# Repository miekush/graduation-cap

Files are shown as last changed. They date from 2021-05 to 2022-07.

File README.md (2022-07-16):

# Graduation Cap
A simple LED sequencer based Graduation Cap

This is a pretty simple LED Graduation cap reference design I made for the upcoming graduation ceremony of my BSEE! It's circuit is based on my [N-Output Sequencer](https://github.com/mkengineering/N_Output_Sequencer) reference design and could be easily modified for other students to use in their own ceremony.

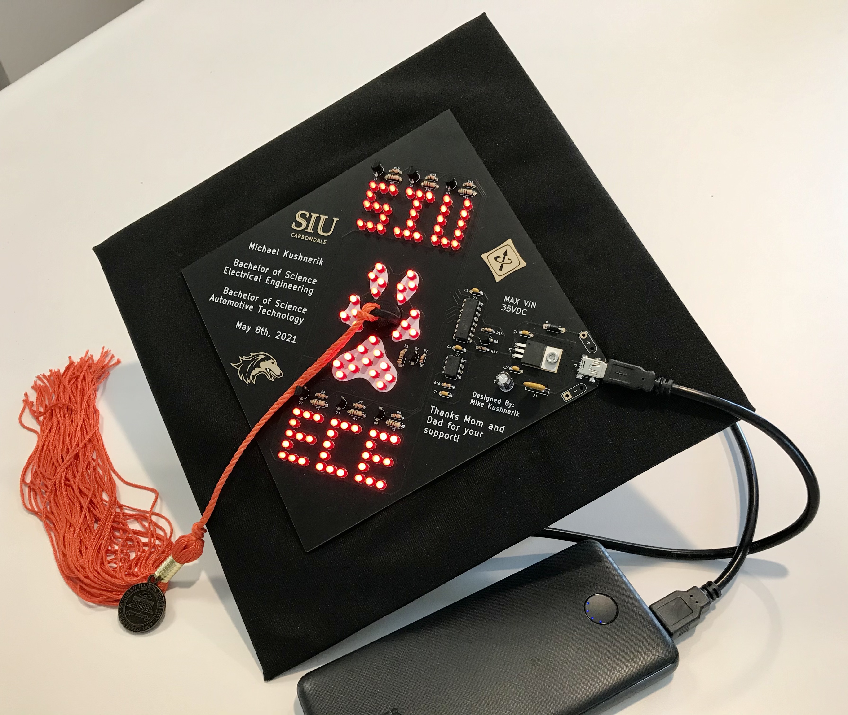
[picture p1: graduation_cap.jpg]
CAP


# Gerber View

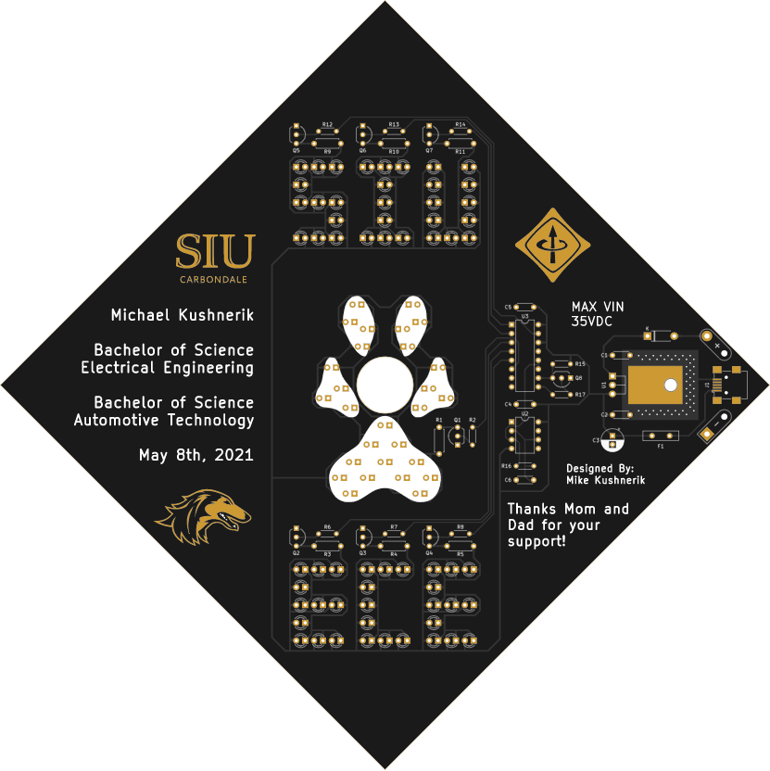
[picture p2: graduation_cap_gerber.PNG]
PCB


# Tassel Holder

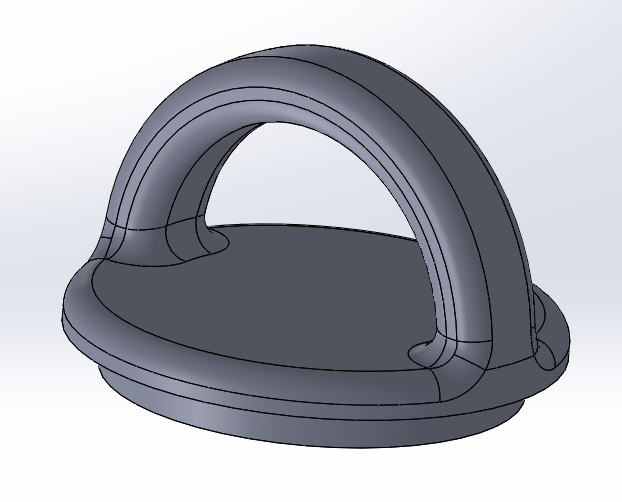
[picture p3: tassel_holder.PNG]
TASSEL


Unfortunatly I wasn't able to get good measurements of the original button that holds the tassel on top of the cap prior to designing the PCB, so the hole I added for it to pass through ended up being too small :cry:. To remedy this, I designed a glue-in 3D printable loop to tie the tassel around. Definitely not ideal but it works great for what it is! Check out the Tassel Holder folder for the solidworks design file and stl!

Designed by Mike Kushnerik (MKE) in KiCad V5

# License

MKE supports the open source hardware community by sharing hardware design files freely on GitHub!

Please support MKE by purchasing products on [Tindie](https://www.tindie.com/stores/mkengineering/)!

Designed by Mike Kushnerik for MKEngineering

Licensed under [Creative Commons Attribution-ShareAlike CC BY-SA 3.0](http://creativecommons.org/licenses/by-sa/3.0/)

All text above must be included in any redistribution!

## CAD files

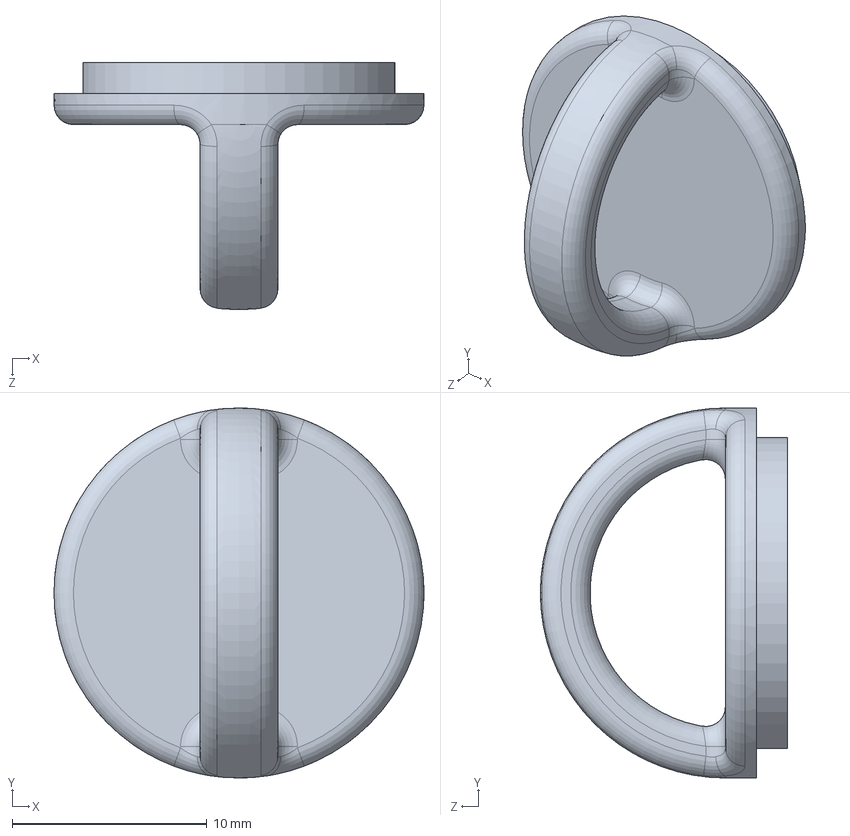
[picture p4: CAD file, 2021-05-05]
Tassel Holder/tassel_holder.SLDPRT
19.0 x 19.0 x 12.7 mm

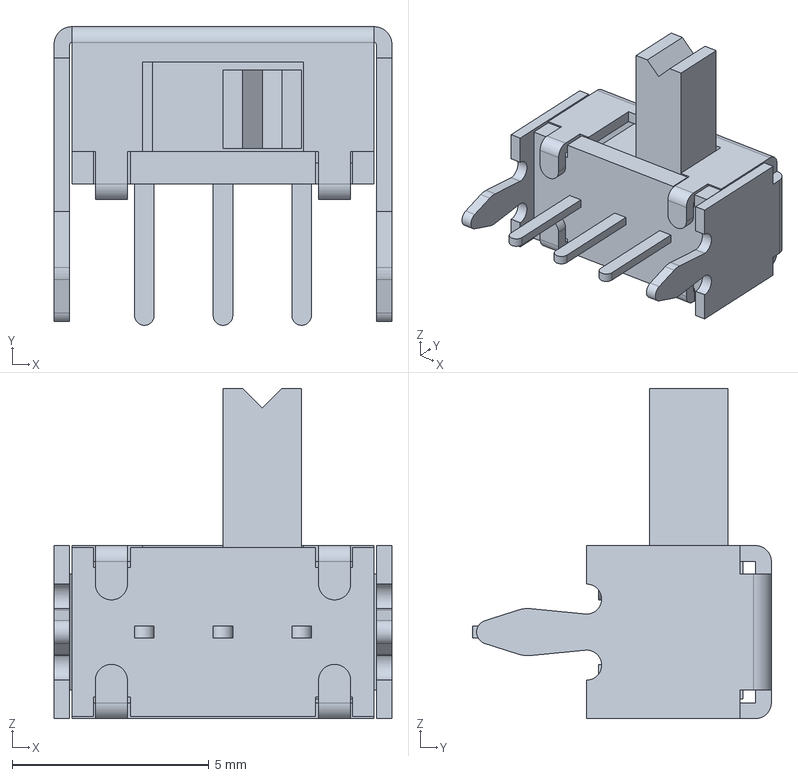
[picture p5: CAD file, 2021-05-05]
3D Models/OS102011MA1QN1.stp
8.60 x 7.60 x 8.40 mm

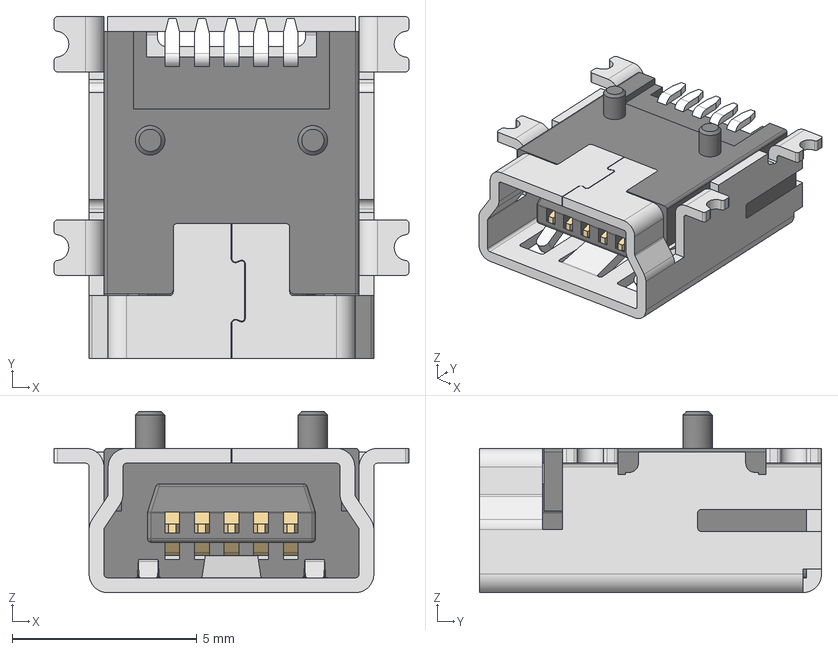
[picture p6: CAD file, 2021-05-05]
3D Models/65100516121_Download_STP_65100516121_rev1.stp
9.60 x 9.25 x 4.90 mm
Shielding
Insulator
Pin_1 x 5

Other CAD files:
Tassel Holder/tassel_holder.STL

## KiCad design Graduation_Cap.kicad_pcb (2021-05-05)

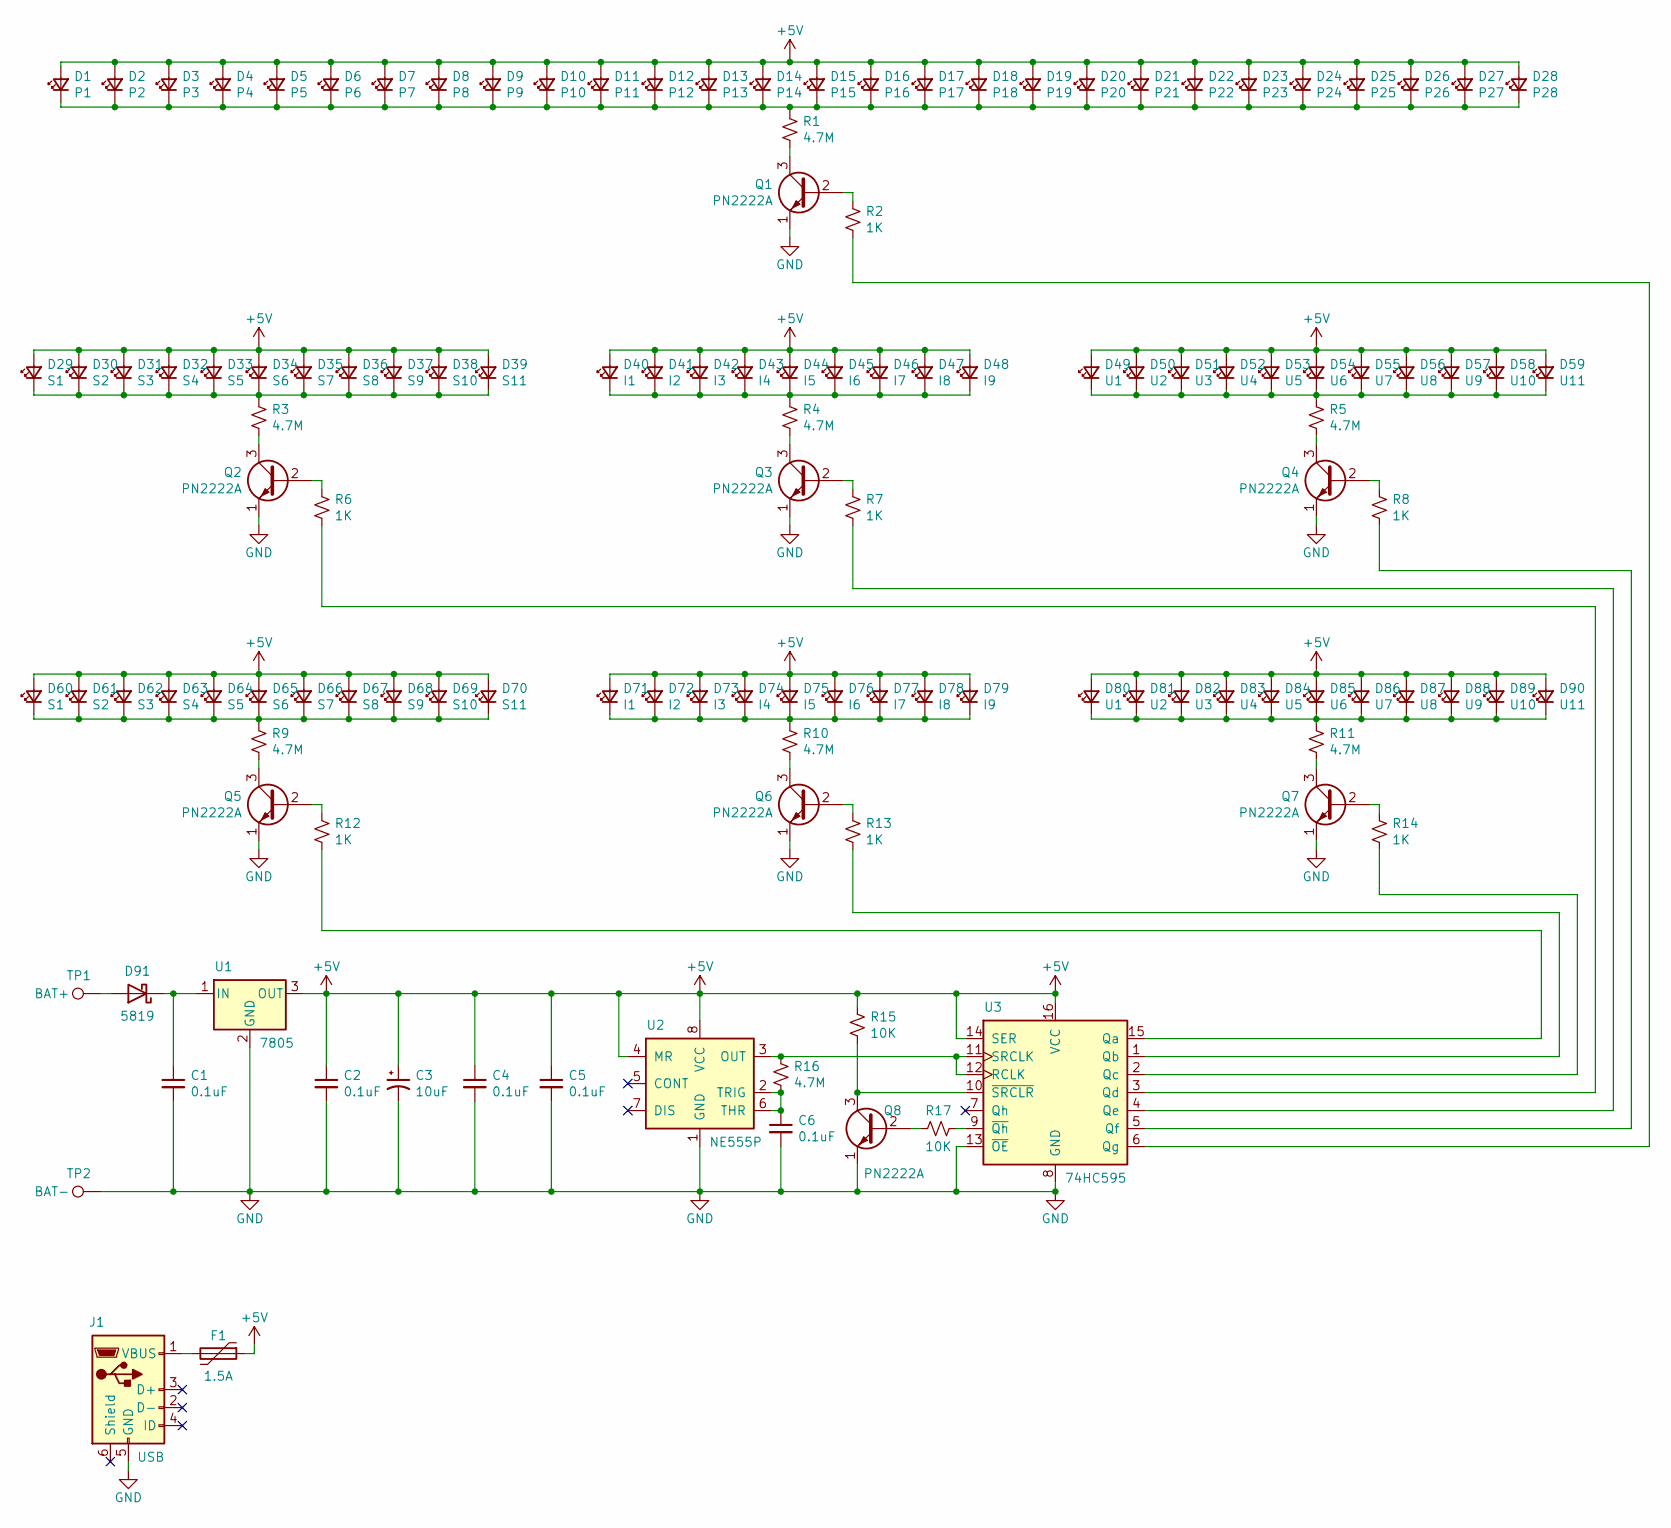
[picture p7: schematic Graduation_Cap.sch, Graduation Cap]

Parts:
C1, C2, C4, C5, C6: 0.1uF; C_Disc_D4.3mm_W1.9mm_P5.00mm
C3: 10uF; CP_Radial_D6.3mm_P2.50mm
D1: P1; LED_D3.0mm
D2: P2; LED_D3.0mm
D3: P3; LED_D3.0mm
D4: P4; LED_D3.0mm
D5: P5; LED_D3.0mm
D6: P6; LED_D3.0mm
D7: P7; LED_D3.0mm
D8: P8; LED_D3.0mm
D9: P9; LED_D3.0mm
D10: P10; LED_D3.0mm
D11: P11; LED_D3.0mm
D12: P12; LED_D3.0mm
D13: P13; LED_D3.0mm
D14: P14; LED_D3.0mm
D15: P15; LED_D3.0mm
D16: P16; LED_D3.0mm
D17: P17; LED_D3.0mm
D18: P18; LED_D3.0mm
D19: P19; LED_D3.0mm
D20: P20; LED_D3.0mm
D21: P21; LED_D3.0mm
D22: P22; LED_D3.0mm
D23: P23; LED_D3.0mm
D24: P24; LED_D3.0mm
D25: P25; LED_D3.0mm
D26: P26; LED_D3.0mm
D27: P27; LED_D3.0mm
D28: P28; LED_D3.0mm
D29, D60: S1; LED_D3.0mm
D30, D61: S2; LED_D3.0mm
D31, D62: S3; LED_D3.0mm
D32, D63: S4; LED_D3.0mm
D33, D64: S5; LED_D3.0mm
D34, D65: S6; LED_D3.0mm
D35, D66: S7; LED_D3.0mm
D36, D67: S8; LED_D3.0mm
D37, D68: S9; LED_D3.0mm
D38, D69: S10; LED_D3.0mm
D39, D70: S11; LED_D3.0mm
D40, D71: I1; LED_D3.0mm
D41, D72: I2; LED_D3.0mm
D42, D73: I3; LED_D3.0mm
D43, D74: I4; LED_D3.0mm
D44, D75: I5; LED_D3.0mm
D45, D76: I6; LED_D3.0mm
D46, D77: I7; LED_D3.0mm
D47, D78: I8; LED_D3.0mm
D48, D79: I9; LED_D3.0mm
D49, D80: U1; LED_D3.0mm
D50, D81: U2; LED_D3.0mm
D51, D82: U3; LED_D3.0mm
D52, D83: U4; LED_D3.0mm
D53, D84: U5; LED_D3.0mm
D54, D85: U6; LED_D3.0mm
D55, D86: U7; LED_D3.0mm
D56, D87: U8; LED_D3.0mm
D57, D88: U9; LED_D3.0mm
D58, D89: U10; LED_D3.0mm
D59, D90: U11; LED_D3.0mm
D91: 5819; D_DO-41_SOD81_P7.62mm_Horizontal
F1: 1.5A; C_Disc_D10.0mm_W2.5mm_P5.00mm
J1: USB; USB_Mini-B_Wuerth_65100516121_Horizontal
Q1, Q2, Q3, Q4, Q5, Q6, Q7, Q8: PN2222A; TO-92_Inline_Wide
R1, R3, R4, R5, R9, R10, R11: 4.7M; R_Axial_DIN0207_L6.3mm_D2.5mm_P7.62mm_Horizontal
R2, R6, R7, R8, R12, R13, R14: 1K; R_Axial_DIN0204_L3.6mm_D1.6mm_P5.08mm_Horizontal
R15, R17: 10K; R_Axial_DIN0204_L3.6mm_D1.6mm_P5.08mm_Horizontal
R16: 4.7M; R_Axial_DIN0204_L3.6mm_D1.6mm_P5.08mm_Horizontal
TP1: BAT+; WIRE_SR_C
TP2: BAT-; WIRE_SR_R
U1: 7805; TO-220-3_Horizontal_TabDown
U2: NE555P; DIP-8_W7.62mm
U3: 74HC595; DIP-16_W7.62mm

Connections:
+5V: C2.1, C3.1, C4.1, C5.1, D1.2 (A), D2.2 (A), D3.2 (A), D4.2 (A), D5.2 (A), D6.2 (A), D7.2 (A), D8.2 (A), D9.2 (A), D10.2 (A), D11.2 (A), D12.2 (A), D13.2 (A), D14.2 (A), D15.2 (A), D16.2 (A), D17.2 (A), D18.2 (A), D19.2 (A), D20.2 (A), D21.2 (A), D22.2 (A), D23.2 (A), D24.2 (A), D25.2 (A), D26.2 (A), D27.2 (A), D28.2 (A), D29.2 (A), D30.2 (A), D31.2 (A), D32.2 (A), D33.2 (A), D34.2 (A), D35.2 (A), D36.2 (A), D37.2 (A), D38.2 (A), D39.2 (A), D40.2 (A), D41.2 (A), D42.2 (A), D43.2 (A), D44.2 (A), D45.2 (A), D46.2 (A), D47.2 (A), D48.2 (A), D49.2 (A), D50.2 (A), D51.2 (A), D52.2 (A), D53.2 (A), D54.2 (A), D55.2 (A), D56.2 (A), D57.2 (A), D58.2 (A), D59.2 (A), D60.2 (A), D61.2 (A), D62.2 (A), D63.2 (A), D64.2 (A), D65.2 (A), D66.2 (A), D67.2 (A), D68.2 (A), D69.2 (A), D70.2 (A), D71.2 (A), D72.2 (A), D73.2 (A), D74.2 (A), D75.2 (A), D76.2 (A), D77.2 (A), D78.2 (A), D79.2 (A), D80.2 (A), D81.2 (A), D82.2 (A), D83.2 (A), D84.2 (A), D85.2 (A), D86.2 (A), D87.2 (A), D88.2 (A), D89.2 (A), D90.2 (A), F1.1, R15.1, U1.3 (OUT), U2.4 (MR), U2.8 (VCC), U3.14 (SER), U3.16 (VCC)
GND: C1.2, C2.2, C3.2, C4.2, C5.2, C6.2, J1.5 (GND), Q1.1 (E), Q2.1 (E), Q3.1 (E), Q4.1 (E), Q5.1 (E), Q6.1 (E), Q7.1 (E), Q8.1 (E), TP2.1, U1.2 (GND), U2.1 (GND), U3.8 (GND), U3.13 (~OE)
unnamed: C1.1, D91.1 (K), U1.1 (IN)
unnamed: C6.1, R16.2, U2.2 (TRIG), U2.6 (THR)
unnamed: D1.1 (K), D2.1 (K), D3.1 (K), D4.1 (K), D5.1 (K), D6.1 (K), D7.1 (K), D8.1 (K), D9.1 (K), D10.1 (K), D11.1 (K), D12.1 (K), D13.1 (K), D14.1 (K), D15.1 (K), D16.1 (K), D17.1 (K), D18.1 (K), D19.1 (K), D20.1 (K), D21.1 (K), D22.1 (K), D23.1 (K), D24.1 (K), D25.1 (K), D26.1 (K), D27.1 (K), D28.1 (K), R1.1
unnamed: D29.1 (K), D30.1 (K), D31.1 (K), D32.1 (K), D33.1 (K), D34.1 (K), D35.1 (K), D36.1 (K), D37.1 (K), D38.1 (K), D39.1 (K), R3.1
unnamed: D40.1 (K), D41.1 (K), D42.1 (K), D43.1 (K), D44.1 (K), D45.1 (K), D46.1 (K), D47.1 (K), D48.1 (K), R4.1
unnamed: D49.1 (K), D50.1 (K), D51.1 (K), D52.1 (K), D53.1 (K), D54.1 (K), D55.1 (K), D56.1 (K), D57.1 (K), D58.1 (K), D59.1 (K), R5.1
unnamed: D60.1 (K), D61.1 (K), D62.1 (K), D63.1 (K), D64.1 (K), D65.1 (K), D66.1 (K), D67.1 (K), D68.1 (K), D69.1 (K), D70.1 (K), R9.1
unnamed: D71.1 (K), D72.1 (K), D73.1 (K), D74.1 (K), D75.1 (K), D76.1 (K), D77.1 (K), D78.1 (K), D79.1 (K), R10.1
unnamed: D80.1 (K), D81.1 (K), D82.1 (K), D83.1 (K), D84.1 (K), D85.1 (K), D86.1 (K), D87.1 (K), D88.1 (K), D89.1 (K), D90.1 (K), R11.1
unnamed: D91.2 (A), TP1.1
unnamed: F1.2, J1.1 (VBUS)
unnamed: Q1.2 (B), R2.1
unnamed: Q1.3 (C), R1.2
unnamed: Q2.2 (B), R6.1
unnamed: Q2.3 (C), R3.2
unnamed: Q3.2 (B), R7.1
unnamed: Q3.3 (C), R4.2
unnamed: Q4.2 (B), R8.1
unnamed: Q4.3 (C), R5.2
unnamed: Q5.2 (B), R12.1
unnamed: Q5.3 (C), R9.2
unnamed: Q6.2 (B), R13.1
unnamed: Q6.3 (C), R10.2
unnamed: Q7.2 (B), R14.1
unnamed: Q7.3 (C), R11.2
unnamed: Q8.2 (B), R17.2
unnamed: Q8.3 (C), R15.2, U3.10 (~SRCLR)
unnamed: R2.2, U3.6 (Qg)
unnamed: R6.2, U3.3 (Qd)
unnamed: R7.2, U3.4 (Qe)
unnamed: R8.2, U3.5 (Qf)
unnamed: R12.2, U3.15 (Qa)
unnamed: R13.2, U3.1 (Qb)
unnamed: R14.2, U3.2 (Qc)
unnamed: R16.1, U2.3 (OUT), U3.11 (SRCLK), U3.12 (RCLK)
unnamed: R17.1, U3.9 (~Qh)

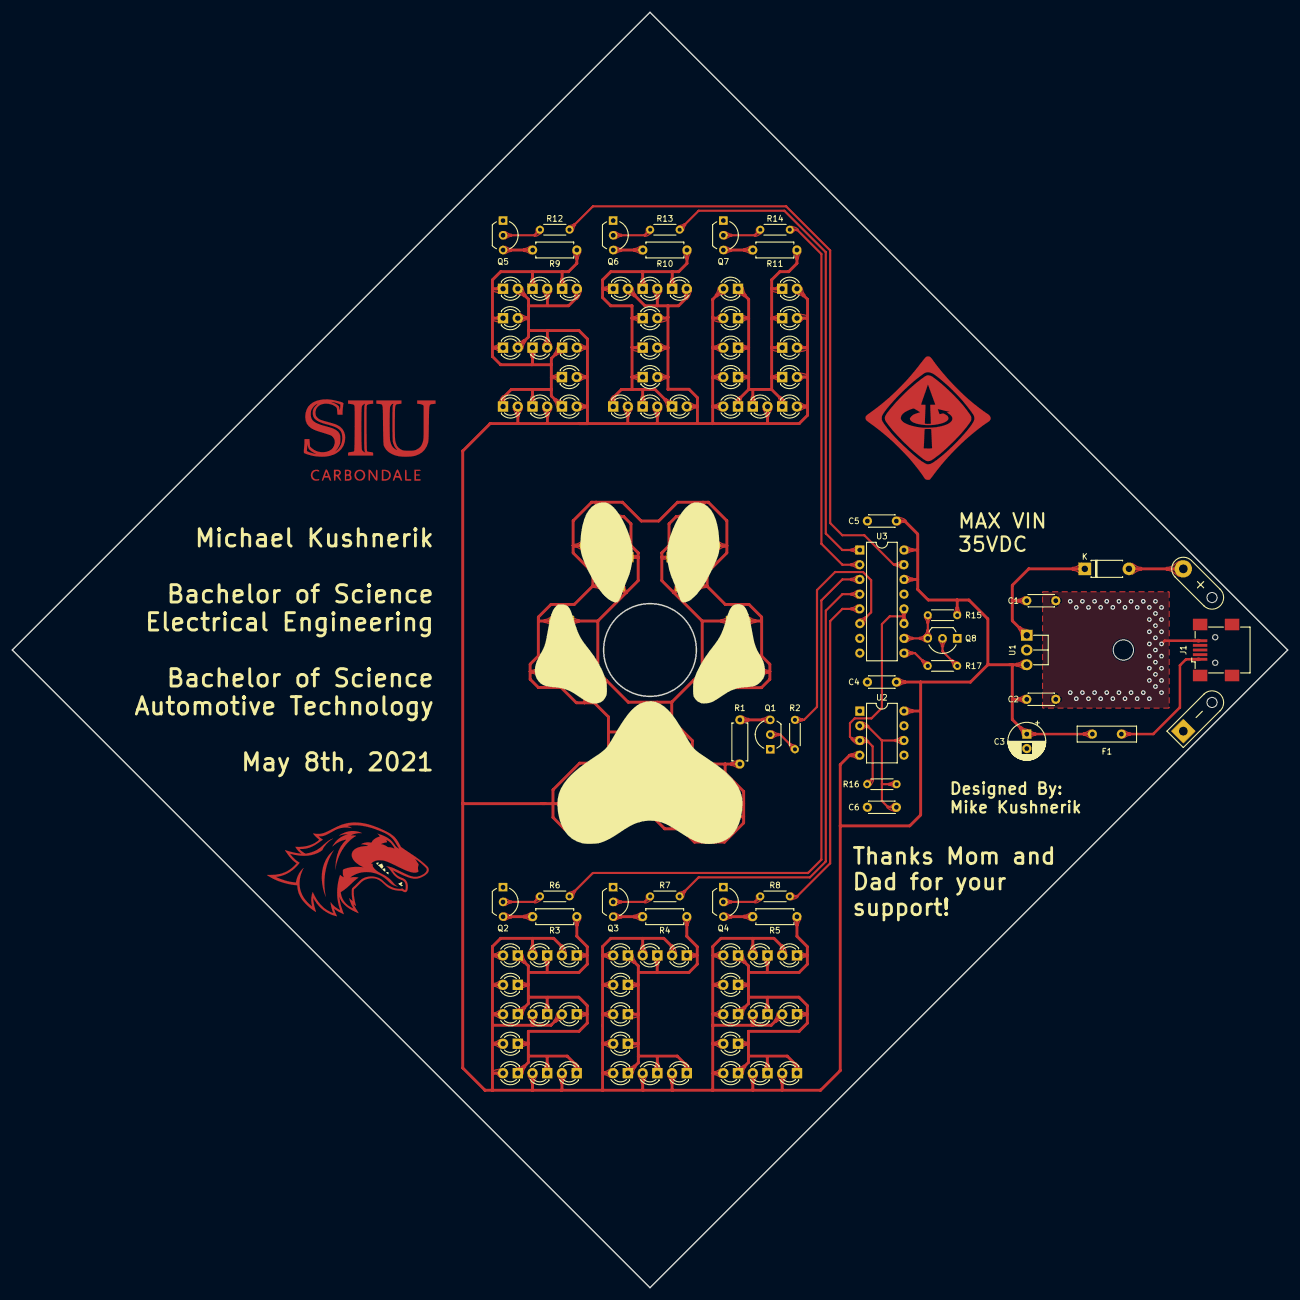
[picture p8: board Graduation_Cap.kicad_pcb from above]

Board: 2 copper layers, 220.0 x 220.0 mm, 129 parts (0 on the bottom side), 38 nets.
